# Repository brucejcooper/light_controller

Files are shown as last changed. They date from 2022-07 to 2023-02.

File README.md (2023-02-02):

# Light Switch firmware
This repo consists of the code that I'm using for my own home automation light switches.

### Theory of operation

1. Devices must operate independently.  If one of these breaks, I don't want the whole house to go dark.
1. Power consumption must be minimised, especially when the light is off.
1. I must be able to control lights via a home automation system (home assistant, or equivalent)
1. It should be as cheap as possible to produce.

So the idea is that none of these devices will have WiFi or ethernet themselves.  That would consume too much current.  Instead, We will use the DALI protocol, which is baked into the transformers that I'll be using for my home.  The circuit for driving a dali signal is very simple, with the exception of isolated power (needed to make the device safe in the presence of a 220V AC wire).  All isolated power systems that I'm aware of use a large amount of quiescent current (on the order of 10s of mA).  This would overload the DALI power supply. 

# Tech notes

## Downloading AVR compiler for attiny 0 series
The default avr-gcc installed by ubuntu doesn't do the 0 series, so I'm stealing the one that Arduino uses

```bash
wget http://downloads.arduino.cc/tools/avr-gcc-7.3.0-atmel3.6.1-arduino7-x86_64-pc-linux-gnu.tar.bz2 -q -O- | bzcat | tar xv
```

This will create a avr-gcc toolchain in the directory `avr` - The Makefile is set up to use this by default.  You can also just run `make download_gcc` to get it.  I will make this query the arduino repository for the latest version in a later update.

This repository is an experiment I am conducting on how best to do a circuit implemented a million times before.  a light switch dimmer (trailing edge). The idea here is to make something that is both efficient and cheap to build.

[Shelly](https://shelly.cloud) produces good, cheap devices, but I'm worried about their vampiric current draw.

# On Matter
I experimented with matter, and got it working quite well.  I have a couple of problems however
1. Its pretty power hungry to run a radio transmitter.  It will use 10s of milliamps for short periods, fairly often.  We might be able to get away with a large capacitor, or we might be able to set it up as a SED so that they wake up less often. Or we might run a second power cble to supply more power.  Seems like overkill, however
2. Transactions can take some time.  Each time a session is set up, a new encryption channel is set up.  This takes time.  I was seeing hundreds of milliseconds of latency, which becomes noticeable.  Now a few hundred milliseconds for a voice command is fine, but when I push a button, I want the light to react instantly.
3. NRF chipsets cost more, and require more external parts

# Keeping it simple
So here's what I've landed on. I want the switches themselves to be as simple as possible, and to use as little power as possible.  It should be sleeping 99.9999% of the time. It shouldn't wake up unless its got something to do (i.e. if something else transmits that is no reason for the rest of the devices to wake up and listen)

In order to facilitate this, configuration will be done via an OOB mechanism, rather than via the DALI protocol, as this will mean that the devices don't need to listen all the time. 

1. The device will sleep all the time
1. Wake up source is NFC, UPDI, or a button press.
1. Do what you need to do, go back to sleep once the button is released.

I have discovered that taking an event driven coding mechanism wastes flash.  I've now simplified it to just do things sequentially in the main loop, and deal with the fact that transmit and receive can take milliseconds.  Button timings will be much longer than this anway, so we can just take a quick break.  In some circumstances, this happens during a debounce period anyway.

The consequence of this is that all configuration needs to be done locally. The idea is to attach a NFC loop that will listen, wake up the chip, and boot into a bootloader - The use of a bootloader allows us to flash over NFC as well.   NFC will also power the chip (temporarily) allowing the device to be configured before being connected to DALI bus.  (But how, we want NFC to work even after DALI is connected.  The chip will put out 2V, so a diode would cause an unacceptable voltage drop.  Do I need a Power Mux e.g TPS2116.  I probably do.  Luckily they are pretty cheap. 

A simpler way to do it is to just use UPDI - but this means adding some sort of connector to the case and also has the same multi-supply problem (which could be fixed with a diode or a switch).

## Bootloader

Needs a mechanism to automatically reboot the MCU when the NFC is being used - We could rely upon the main firmware to detect the field then reboot itself, but what if it crashes?  Maybe the WDT?

Each FD transition from high -> low (SRAM filled up) could be turned into a quick pulse on RESET (minimum requirement of 2.5us), using a monostable multivibrator (SN74LVC1G123).  The bootloader now boots each time a FD goes low, but we might need multiple transactions to flash the device. SRAM can only store 64 bytes at a time.  We don't want to boot into a half written flash, so perhaps the Bootloader needs to check an EEPROM value.  

If there were two slots, we could check if we're complete or not.  We'd repeatedly reboot into the old firmware until the last block was written. 

## WDT
Do I need a WDT?  Its probably a good idea.

# Pins
* 2 Voltage supply
* 1 Reset/UPDI
* 5 switches
* 2 DALI TX/RX
* 4 left over. Not quite enough for LEDs. 

GPIO expander for LEDs? Or just go to 20 pin package (which would also get us I2C). Attiny406 is $1.26.  Attiny404 is $1.05 so $0.21 difference. Much cheaper than a separate chip.

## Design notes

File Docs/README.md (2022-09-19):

# Glossary

* Control Gear - A light
* Input Devices - A button, or a light sensor etc..
* Control Devices / Application controller - A bus master

# Hardware

* [RasPi Hat](https://www.shop.atxled.com/products/dali-hat-for-raspberry-pi-b-and-b?variant=31063289430131)

# Some links

* [Microchip DALI Commands](https://onlinedocs.microchip.com/pr/GUID-0CDBB4BA-5972-4F58-98B2-3F0408F3E10B-en-US-1/index.html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)
* [Python DALI code](https://github.com/sde1000/python-dali)
* [TI system](https://www.ti.com/lit/an/slaa422a/slaa422a.pdf) - Code in ti subdirectory

# DALI-2 stuff
eDali is Tridonic proprietary 25 bit command.  Is deprecated.

Normal control gear is 24 bit command stuff.

24 bit frames exchanged betwen app controller and input devices.

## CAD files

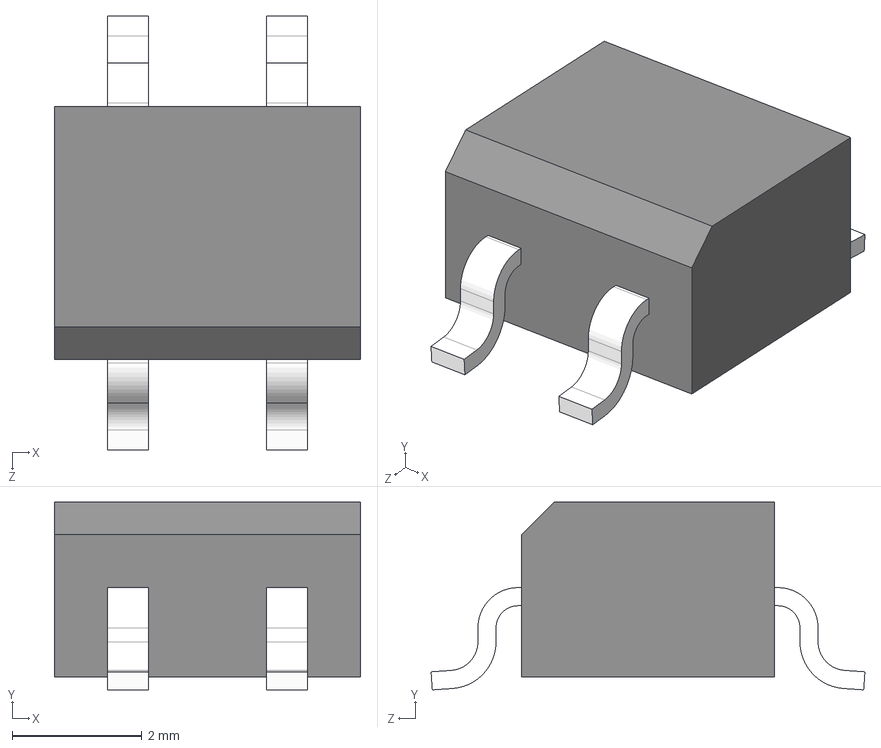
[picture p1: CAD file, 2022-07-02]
kicad/imported_modules/SOIC245P670X290-4N.step
4.72 x 2.90 x 6.70 mm

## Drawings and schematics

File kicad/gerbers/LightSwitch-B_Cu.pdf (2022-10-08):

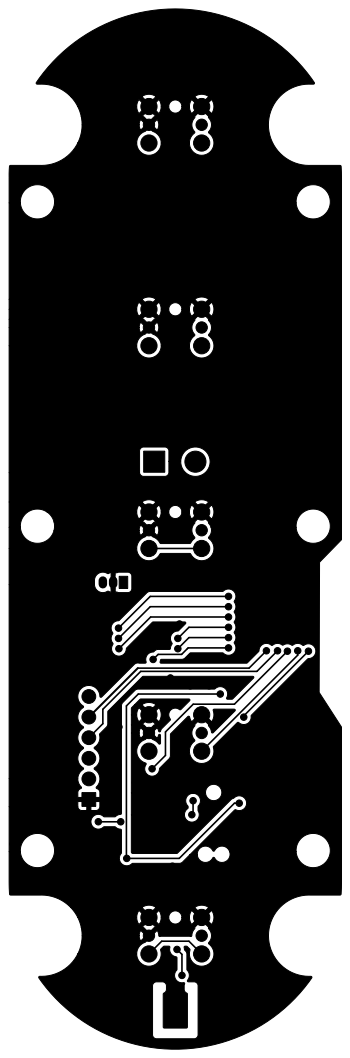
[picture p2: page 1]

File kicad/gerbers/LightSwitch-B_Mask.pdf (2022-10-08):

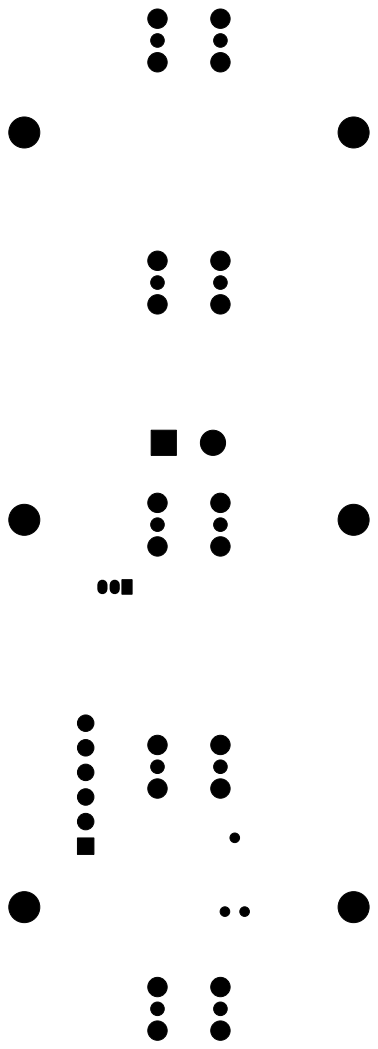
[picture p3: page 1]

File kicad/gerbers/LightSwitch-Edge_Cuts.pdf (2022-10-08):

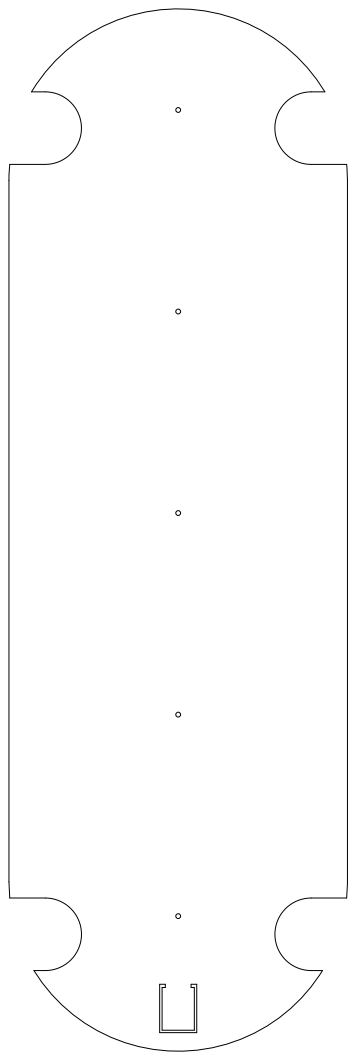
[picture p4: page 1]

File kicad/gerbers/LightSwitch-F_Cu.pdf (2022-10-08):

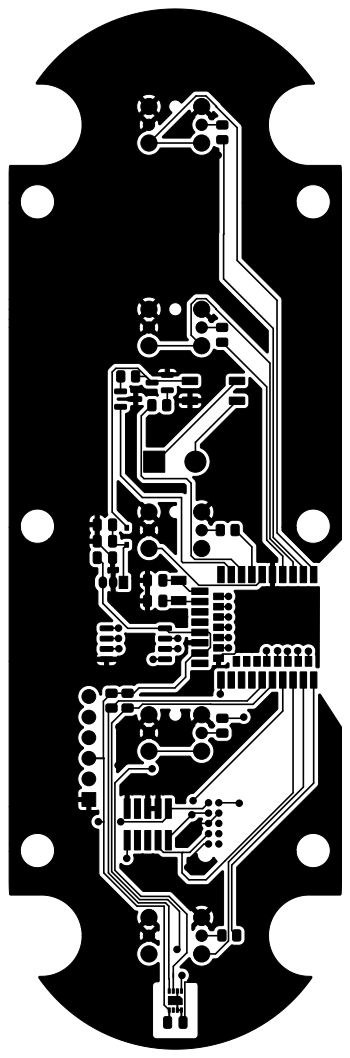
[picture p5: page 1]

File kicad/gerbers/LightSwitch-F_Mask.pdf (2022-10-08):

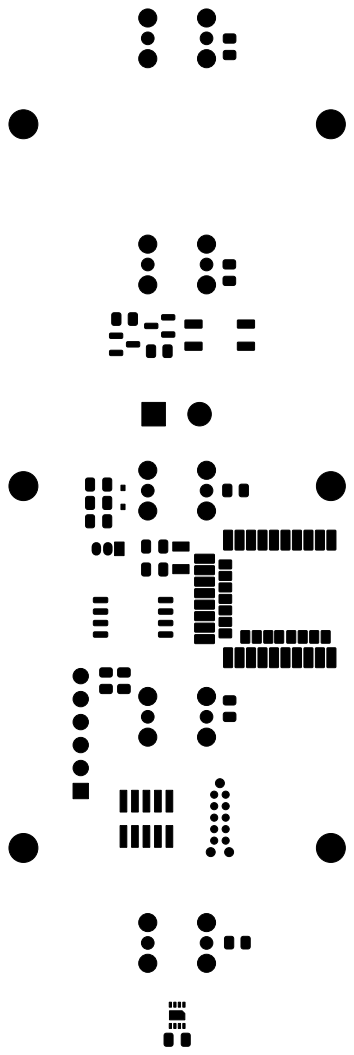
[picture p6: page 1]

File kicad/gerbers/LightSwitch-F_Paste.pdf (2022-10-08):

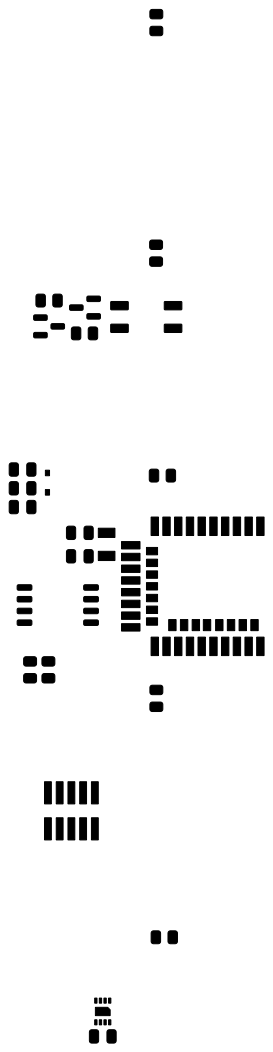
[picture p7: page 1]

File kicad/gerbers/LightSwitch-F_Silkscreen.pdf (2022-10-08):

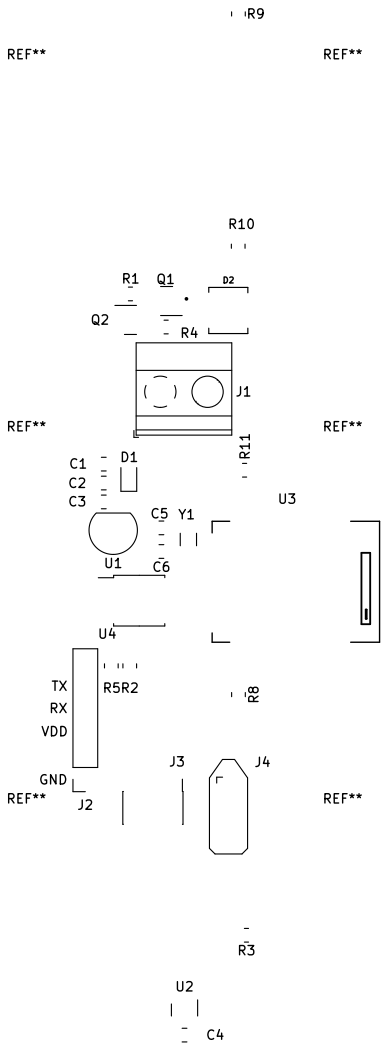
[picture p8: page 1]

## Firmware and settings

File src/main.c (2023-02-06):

#include <avr/io.h>
#include <util/delay.h>
#include <inttypes.h>
#include <avr/interrupt.h>
#include <avr/sleep.h>
#include <avr/pgmspace.h>
#include <avr/wdt.h>
#include <util/atomic.h>
#include <stdbool.h>
#include <stdlib.h>
#include <string.h>
#include "cmd.h"
#include "buttons.h"
#include "config.h"


void reset() {
    // Write a bit into the SWRR to reboot the device (to the bootloader).
    RSTCTRL.SWRR = RSTCTRL_SWRE_bm;
}

static inline void set_wdt(uint8_t val) {
    while (WDT.STATUS & WDT_SYNCBUSY_bm) {
        ;
    }
    CCP = CCP_IOREG_gc;
    WDT.CTRLA = val;
}

int main(void) {
    // The longest WDT period we can set.
    set_wdt(WDT_PERIOD_8KCLK_gc);
    // console_init();

    // Set the DALI output (PB2) as an output, initially set to zero out (not shorted)
    PORTB.OUTCLR = PORT_INT2_bm;
    PORTB.DIRSET = PORT_INT2_bm;

    // Set up the DALI input (PA7) using the Analog Comparator with reference of 0.55V
    // This makes it trigger sooner than if we were doing digital I/O, as it has a much lower threshold
    VREF.CTRLA = VREF_DAC0REFSEL_0V55_gc;
    PORTA.PIN7CTRL  = PORT_ISC_INPUT_DISABLE_gc; // Disable Digital I/O, so that it doesn't mess with the impedence
    AC0.MUXCTRLA = AC_MUXNEG_VREF_gc | AC_MUXPOS_PIN0_gc;
    AC0.CTRLA = AC_HYSMODE_OFF_gc | AC_ENABLE_bm; // Enable the AC.    


    // Turn on the RTC and PIT
    RTC.CLKSEL = RTC_CLKSEL_INT1K_gc; // Slow down buddy.
    RTC.PITCTRLA = RTC_PERIOD_CYC4096_gc | RTC_PITEN_bm; // Set the PIT to go off at least once per maximum WDT period.
    while (RTC.STATUS & RTC_CTRLABUSY_bm) {
        ;
    }
    RTC.CTRLA = RTC_RTCEN_bm | RTC_PRESCALER_DIV1_gc;

    set_sleep_mode(SLEEP_MODE_PWR_DOWN);
    buttons_init();
    sei();

    while (1) {
        if (poll_buttons()) {            
            // log_info("Sleep");
            // Enable interrupts to wake us back up
            PORTA.PIN6CTRL = PORT_PULLUPEN_bm | PORT_ISC_LEVEL_gc;
            RTC.PITINTCTRL = RTC_PI_bm;
            sleep_mode();            
            RTC.PITINTCTRL = 0;
            PORTA.PIN6CTRL = PORT_PULLUPEN_bm; 
        }
    }
    return 0;
}

// we don't expect the PIT to do anything except wake us up, but if there isn't an ISR,
// odd things happen
ISR(RTC_PIT_vect) {
    RTC.PITINTFLAGS = RTC_PI_bm;
}

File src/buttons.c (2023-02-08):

#include <avr/io.h>
#include <util/delay.h>
#include <inttypes.h>
#include <avr/interrupt.h>
#include <avr/sleep.h>
#include <avr/wdt.h>
#include <util/atomic.h>
#include <stdbool.h>
#include <string.h>
#include "buttons.h"
#include "config.h"
#include <stdlib.h>
#include "cmd.h"


// For test board, switch is on PA6
#define SWITCH_PORT PORTA
#define MS_TO_RTC_TICKS(m) (m * 1024 / 1000)
struct button_t;

typedef enum {
    BTN_STATE_RELEASED,
    BTN_STATE_DEBOUNCING,
    BTN_STATE_PRESSED,
    BTN_STATE_LONGHELD,
    BTN_STATE_RELEASE_DEBOUNCE,
    BTN_STATE_RELEASED_WAIT_FOR_REPRESS,
} button_state_t; 


typedef enum {
    SLEEP_STATE_PROCESSING,
    SLEEP_STATE_WAITING,
    SLEEP_STATE_SLEEP_READY
} sleep_state_t;


static sleep_state_t sleepState = SLEEP_STATE_PROCESSING;
static uint16_t idleTimeout;


typedef void (*state_handler_t)(struct button_t *btn, const uint8_t button_level);
typedef struct button_t {
    // Index of the button.
    uint8_t index;

    // Dimming Direction.
    dali_gear_command_t direction;

    // RTC timeout for next 
    uint16_t timeout;

    // Bit mask for the pin
    uint8_t mask;

    // The state handler.
    button_state_t state;

    // The last read light level for this target.
    uint8_t light_level;
} button_t;

static void released(button_t *btn, const uint8_t button_level);
static void pressed(button_t *btn, const uint8_t button_level);
static void long_pressed(button_t *btn, const uint8_t button_level);
static void wait_for_repress(button_t *btn, const uint8_t button_level);
static void long_pressed(button_t *btn, const uint8_t button_level);

static button_t buttons[NUM_BUTTONS] = {
    {
        .index = 0,
        .state = BTN_STATE_RELEASED,
        .mask = PIN6_bm,
        .light_level = 0,
        .direction = DALI_CMD_DOWN,
        .timeout = 0,
    }
};


void buttons_init() {
    // Set up pins with pullup, with no interrupt.  the interrupt will be turned on while sleeping.
    SWITCH_PORT.PIN6CTRL = PORT_PULLUPEN_bm;

    // Set all the pins as inputs.
    SWITCH_PORT.DIRCLR = PIN6_bm;
}

static inline bool check_timeout(uint16_t t) {
    return ((int16_t) (RTC.CNT - t)) >= 0;
}

static inline bool is_timer_expired(button_t *btn) {
    return check_timeout(btn->timeout);
}


static void send_dali_cmd_no_response(button_t *btn, dali_gear_command_t cmd) {
    uint8_t dummy;
    read_result_t res = send_dali_cmd(config->targets[btn->index], cmd, &dummy);
    if (res != READ_NAK) {
        // What do we do?
    }
}

static uint8_t send_dali_query(button_t *btn, dali_gear_command_t cmd, uint8_t defaultVal) {
    uint8_t val;
    read_result_t res = send_dali_cmd(config->targets[btn->index], cmd, &val);
    if (res != READ_VALUE) {
        return defaultVal;
    }
    return val;    
}




static inline void execute_dim(button_t *btn) {
    send_dali_cmd_no_response(btn,  btn->direction);
}


static inline void do_press(button_t *btn) {
    // Its been pressed.
    btn->state = BTN_STATE_DEBOUNCING;
    btn->timeout = RTC.CNT + MS_TO_RTC_TICKS(20);
}

static void debouncing(button_t *btn, const uint8_t button_level) {
    if (button_level) {
        // Bounce!  We ignore small pulses (less than the debounce timer) to be noise resistant.
        btn->state = BTN_STATE_RELEASED;
    } else if (is_timer_expired(btn)) {
        // Graduated to pressed. 
        btn->state = BTN_STATE_PRESSED;
        btn->timeout = RTC.CNT + config->doublePressTimer;

        // ask the ballast its current level.
        // this takes some time (15-20 ms, including post response delay)
        btn->light_level = send_dali_query(btn, DALI_CMD_QUERY_ACTUAL_LEVEL, 0);     
    }
}


static void released(button_t *btn, const uint8_t button_level) {
    if (!button_level) {
        do_press(btn);
    }
}

static void pressed(button_t *btn, const uint8_t button_level) {
    if (button_level) {
        // Its been released - send out either an off or an on command, depending ont he current level
        send_dali_cmd_no_response(btn, btn->light_level ? DALI_CMD_OFF : DALI_CMD_GO_TO_LAST_ACTIVE_LEVEL);
        // The command will have taken a little over 10 milliseconds.  This is effectively our debounce period.
        btn->state = BTN_STATE_RELEASED;
    } else if (is_timer_expired(btn)) {
        btn->state = BTN_STATE_LONGHELD;
        btn->timeout = RTC.CNT + config->repeatTimer;
        if (btn->light_level == 0) {
            // We can't dim or brighten if we're not on, so turn it on, and find out what the current level is.
            send_dali_cmd_no_response(btn, DALI_CMD_GO_TO_LAST_ACTIVE_LEVEL);
            btn->light_level = send_dali_query(btn, DALI_CMD_QUERY_ACTUAL_LEVEL, 0);     
        }
        // TODO is there a way this can be hidden something else?  Perhaps during the long press delay?
        uint8_t minLevel = send_dali_query(btn, DALI_CMD_QUERY_MIN_LEVEL, 0);
        // If we're already at minimum, start out brightening, otherwise start dimming
        btn->direction = btn->light_level <= minLevel ? DALI_CMD_UP : DALI_CMD_DOWN;
        execute_dim(btn);
    }
}

static void long_pressed(button_t *btn, const uint8_t button_level) {
    if (button_level) {
        // It was released. Do some debouncing.
        btn->state = BTN_STATE_RELEASE_DEBOUNCE;
        btn->timeout = RTC.CNT + MS_TO_RTC_TICKS(10); 
    } else if (is_timer_expired(btn)) {
        // Its been held long enough now for a repeat.
        btn->timeout = RTC.CNT + config->repeatTimer; 
        execute_dim(btn);
    }
}

static void release_debounce(button_t *btn, const uint8_t button_level) {
    if (is_timer_expired(btn)) {
        btn->state = BTN_STATE_RELEASED_WAIT_FOR_REPRESS;
        btn->timeout = RTC.CNT + config->repeatTimer;
    }
}

static void wait_for_repress(button_t *btn, const uint8_t button_level) {
    if (!button_level) {
        // Its a repress (Kinda like a double click, but after a long hold)
        // TODO If you immediately repress, I wonder if going directly to max (or min) would be a good idea.  An easy way of getting to an extreme without having to wait. 
        btn->direction = btn->direction == DALI_CMD_UP ? DALI_CMD_DOWN : DALI_CMD_UP;
        btn->timeout = RTC.CNT + config->repeatTimer; 
        btn->state = BTN_STATE_LONGHELD;
        execute_dim(btn);
    } else if (is_timer_expired(btn)) {
        btn->state = BTN_STATE_RELEASED;
    }
}
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

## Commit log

2021-12-05 Works with diode clamped input
2021-12-06 Added Circuit
    [LightSwitch.kicad_pcb, LightSwitch.sch]
2021-12-06 Some small circuit changes
    [LightSwitch.sch]
2021-12-06 more circuit changes
    [LightSwitch.sch]
2022-04-29 Switch to Attiny804, and got it working with its own (stolen from arduino) compiler
2022-06-12 Working button debouncing, and written (but not tested) DALI
2022-06-13 Fixed clock, and made DALI transmission use a timer
    [buttons.c, main.c]
2022-07-02 Parking stuff, so I can contemplate the use of a nrf52840 _with_ DALI
    [LightSwitch.kicad_pcb, LightSwitch.kicad_sch, SOIC245P670X290-4N.step]
2022-08-08 Updated with NRF52840 version. Modded since sending to OSHPark
    [LightSwitch.kicad_pcb, LightSwitch.kicad_sch]
2022-08-26 Changed DALI transmit to use timer based bit flips of the GPIO
    [buttons.c, main.c]
2022-09-05 Switch to using voltage divider for reading, rather than a transistor. This gives us a specific voltage threshold to work with
2022-09-24 Staging for move to Raspberry Pi
2022-10-08 latect schematic
    [LightSwitch-B_Cu.gbr, LightSwitch-B_Mask.gbr, LightSwitch-B_Paste.gbr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]
2022-12-05 Fixed bugs in timing. USB variant now looking a lot like the normal one... Will merge later
    [main.c]
2022-12-21 More bug fixes. Now dealing with timeout accuracy
    [buttons.c]
2022-12-23 Works pretty well now. Pushing the button toggles the configured lamp. Next is getting it to be discoverable
2023-01-30 Added delay between write and read, as this was causing issues
    [cmd.c]
2023-02-04 Fixed bugs caused by missing ISRs when sleeping
    [buttons.c, cmd.c, main.c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]
2023-02-06 Fixed bug causing some button presses to be ignored. it was polling after being woken up, which caused a debuonce problem
    [buttons.c, main.c]
2023-03-19 Refactoring NFC stuff. might park it, as it is too susceptible to metal interference. Will experiment again wth BLE
    [boot.c, main.c, nfc.c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]
